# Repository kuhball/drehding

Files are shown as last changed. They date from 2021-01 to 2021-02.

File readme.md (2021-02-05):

# Dreh Ding
An optical illusion.

- [platformio/](platformio/) - the project's code; developed with [platform.io](https://platformio.org/) framework
- [arduinoide/](arduinoide/) - code for the Arduino IDE
	- [tests/](arduinoide/tests/) - component tests, mainly for debugging purposes
	- [legacy/](arduinoide/legacy/) - legacy code, kept to look up old coding patterns
	- [sandbox/](arduinoide/sandbox/) - various code snippets in various states
- [ui/](ui/) - python template code to communicate with the microcontroller
- [fritzing/](fritzing/) - hardware connection diagrams and components created with [Fritzing](https://fritzing.org/)
- [images/](images/) - images for the readme

### Documentation
- [flasheffects.md](flasheffects.md) - A collection of different flash effects that could be programmed.
- [exhibition.md](exhibition.md) - Collection of ideas for installations and performances based on the project.
- [notes.md](notes.md) - Various notes and remarks which have no better place.
- [ideas.md](ideas.md) - Random ideas and notes and such. Can be deleted at any time.

## The project
**Dreh Dings** develops around the [stroboscopic effect](https://en.wikipedia.org/wiki/Stroboscopic_effect). The idea is to place a rotating geometrical object (e.g. a cube) in the centre of a stage and light it at specific intervals with flashes from a number of surrounding LED lights. By varying the flash intervals, various optical illusion effects can be generated. See the following images for a high level schema:

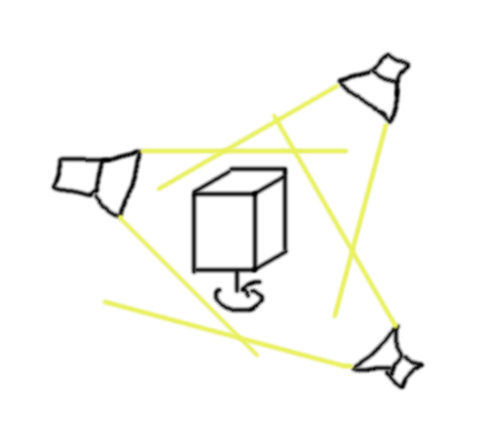
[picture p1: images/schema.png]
High level schema


The project is realized through a number of hardware components and a microprocessor for controlling. Basically, the object turns on a motor whose speed we can modulate. The motor additionally contains a hall sensor (speedometer, clock) to measure the rotation speed. The hall sensor's signal is then used to flash the LEDs at the desired intervals.

The most simple flash configuration is be to flash a single LED always at exactly the same fraction of the object's rotation. Since the object is only illuminated when in the same position, it appears stationary to the observer.

More advanced and interesting flash configurations are also possible.

## Set-up
Navigate to [arduinoide/releases/](arduinoide/releases/) and follow the instructions.

## The software
Coding is done with the [platform.io](https://platformio.org/) framework. Ideally integrated into VSCode as IDE. For every release, an Arduino IDE compatible source code folder is also created.

## The hardware
See [hardware.md](hardware.md).

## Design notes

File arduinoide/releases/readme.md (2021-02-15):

# Releases
Collection of releases for fast deployment.

## How-to
This section describes how to set up the project and get it to run the fast way.

1. Pick a release below.
2. Set-up the hardware according to the connection diagram of the release
3. Download the files in the releases `Drehdings/` folder
4. Open the `Drehdings.ino` with the Arduino IDE
5. Change the settings in the configuration section to match your set-up
6. Compile and upload to the microcontroller
7. Enjoy!

## Releases

### [2021-03-15 Glossy Grape](20210215GlossyGrape/)
A set-up with three LEDs, a rotary encoder to control the motor speed, and a push button to loop through the effects. Does not support gear ratio. Only includes a small number of effects. Mainly intended to try the configuration.

**Usage:**
- Turn knob of rotary encoder to start the motor and to control the motor speed.
- Use push button on rotary encoder to iterate through the LEDs' effects.

**Changelog:**
- switched from Encoder.h to SimpleEncoder.h library
- added Effect-class based LED effects
- fixed glitches that sometimes lead to memory leaks
- added all dependencies directly to the code to avoid Arduino IDE library version issues

**Diagram:**
Same as for release `20210205AbsoluteZero` below.

### [2021-03-05 Absolute Zero](20210205AbsoluteZero/)
A set-up with three LEDs, a rotary encoder to control the motor speed, and a push button to loop through the effects. Does not support gear ratio. Only includes a small number of effects. Mainly intended to try the configuration.

**Usage:**
- LED1 and LED2 will create two slowly turning images of the objects turning in opposite directions.
- Turn knob of rotary encoder to start the motor and to control the motor speed.
- Use push button on rotary encoder to alternate the third LEDs point of flicker (from 0 to 45 degree and back)

**Diagram:**
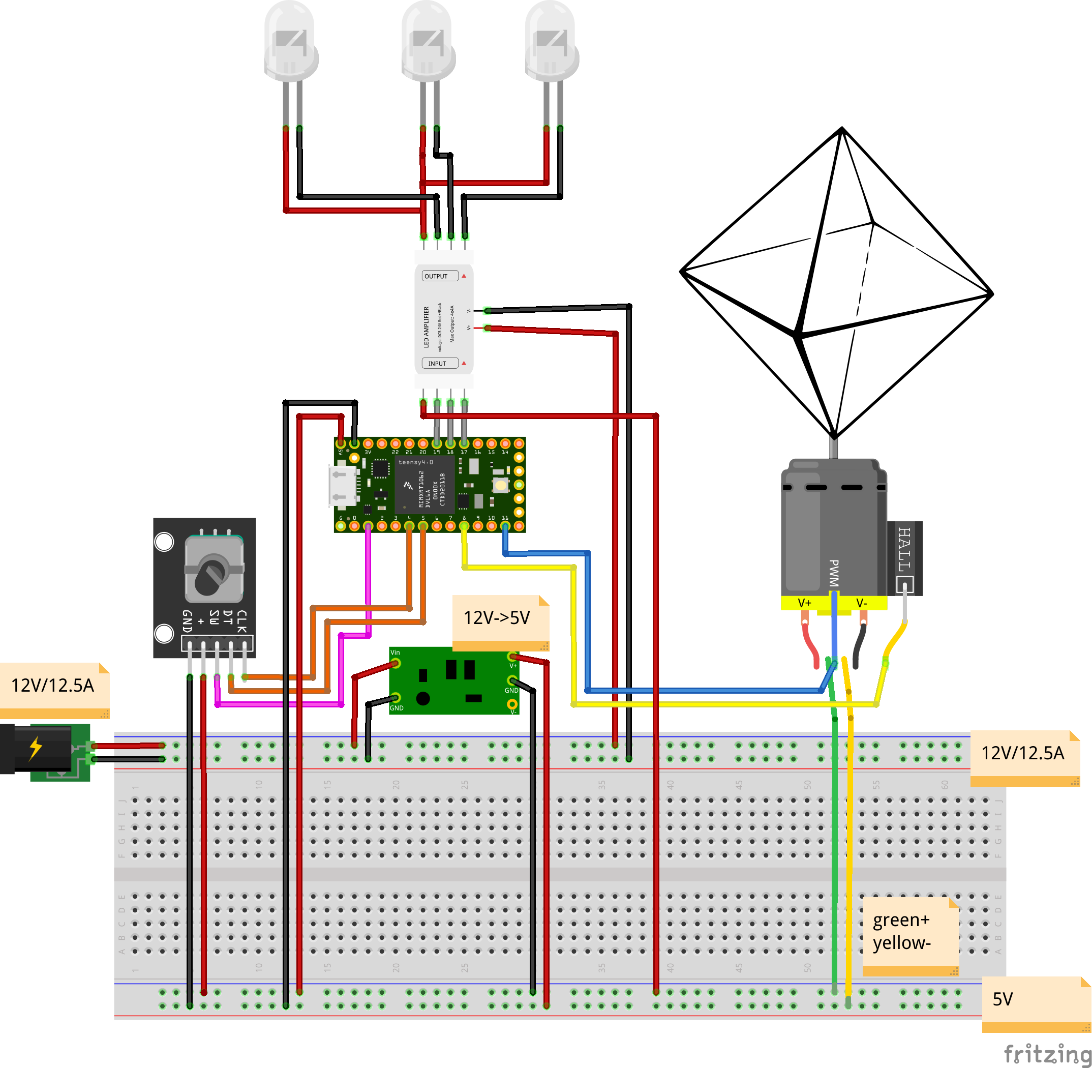
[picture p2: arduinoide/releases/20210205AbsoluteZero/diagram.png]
Connection diagram


## Create a new release

1. Make sure that the code is working well (testing)
2. Choose a name, all releases are named after [colours](https://en.wikipedia.org/wiki/Lists_of_colors)
3. Create a folder under `arduino/releases/` names `YYYYMMDDColour`
4. Copy the `main.cpp` and all library files (`.h` and `.cpp`) to a `Drehdings/` subdirectory
5. Rename `main.cpp` to `Drehdings.ino`
6. Open `Drehdings.ino` in Arduino IDE, compile, upload, and test
7. Create a hardware connection diagram with [Fritzing](https://fritzing.org/) and export as PNG/SVG to release folder
8. Create a new release section in this file and describe the release

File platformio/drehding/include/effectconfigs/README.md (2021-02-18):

# Effect configs
A collection of configuration files that define effect sequences for the project. Allows for easy switching between different effect configurations.

To select one, include it in the `main.cpp` with

```cpp
#include "effectconfigs/example.h" 
```

## How to make your own
See [example.h](example.h) for a detailed example. Then simply copy the file and adapt to your needs.

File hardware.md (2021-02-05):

# Hardware

## The connection diagram

Connection diagram

## The components

#### The microcontroller
The microcontroller lies at the core of the project. Here, all the input signal are gathered and the output signals send to the various components to ensure a seamless interaction. Any programmable microprocessor with digital and at least one analogue PIN can be employed. We use [Arduinos](www.arduino.cc) variants, specifically the [Teensy 4.0](https://www.pjrc.com/store/teensy40.html) for their size and simplicity.

#### The DC motor
The [DC motor](https://en.wikipedia.org/wiki/DC_motor) rotates the illuminated object. It should be powerful enough to drive it fitfully. And it should be of sufficient quality to minimize vibrations, as these weaken the stroboscopic effect. We also want to control the motor's rotation speed, which is usually realized through a [PWM](https://en.wikipedia.org/wiki/Pulse-width_modulation) input. Additionally, the motor should contain a speedometer, usually a hall sensor (see below for more details on this component). All of these controls are already included in modern fan motors, which are therefore our motors of choice.

A typical specification sheet of a fan motor can e.g. look as follows:

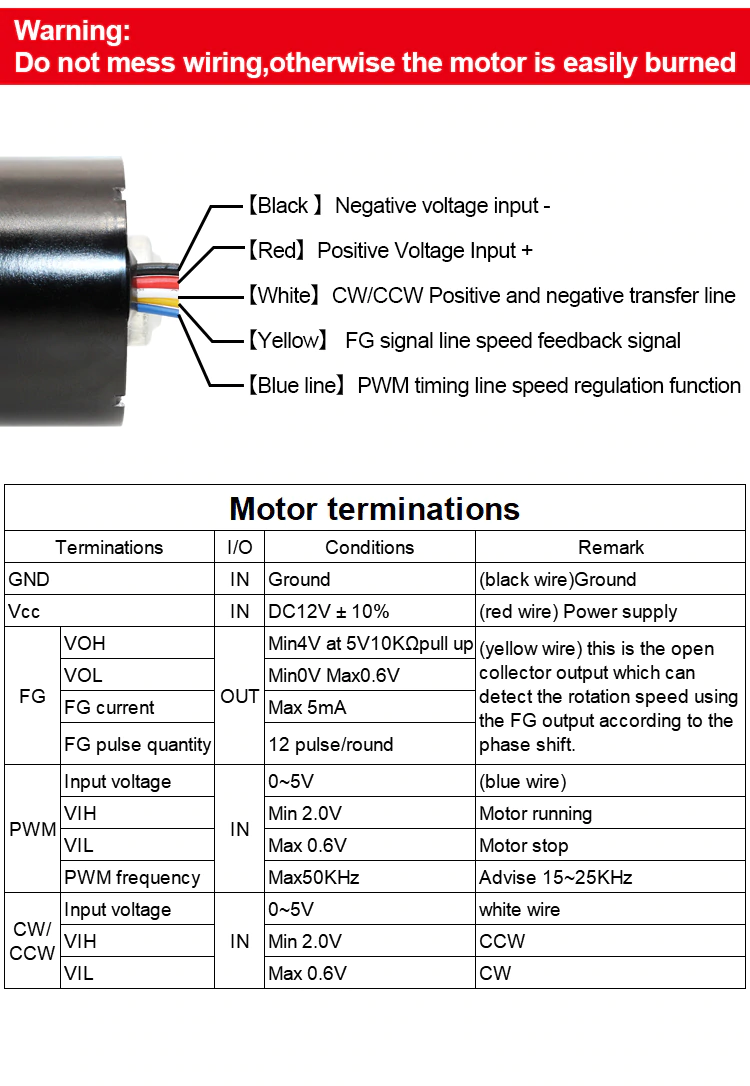
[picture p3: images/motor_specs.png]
Motor specifications example


##### Power supply
Here the black and red wires. Arduino's can only supply 3V or 5V, hence you will need an additional power supply to drive the motor and the LEDs. Take care to keep the power lines separated: Supplying too high voltage to the Arduino or a voltage over 3V to one of the Arduino's input pins can destroy the processor. All ground wires should be connected to the same line, though.

##### Speedometer / hall sensor
Here the yellow wire. Analogue output that sends a PWM signal. See below for more details.

##### Rotation speed control
Here the blue wire. Analogue input that expects a PWM signal. This signal is then averaged, and [the average voltage received determines the motor's rotation speed](https://www.electronics-tutorials.ws/blog/pulse-width-modulation.html).

We employ a rotary encoder to control the motor speed.

##### Rotation direction control
Here the white wire. Digital input that expects a high or low signal. Depending on the signal, the motor turn clockwise (CW) or counter-clockwise (CCW). We do not make use of this wire.

#### The (incremental) rotary encoder
A [rotary encoder](https://en.wikipedia.org/wiki/Rotary_encoder) is essentially a turning knob. We can capture in which direction it turns and change a variable accordingly. A detailed description of it' working can be found [her](https://lastminuteengineers.com/rotary-encoder-arduino-tutorial/).

Here we use it to control the motor speed by changing the PWM signal's duty cycle.

Since the rotary encoders signal is not very clean, it cannot be used for discrete changing of states, as e.g. controlling the LED effects. Even with software de-bouncing activated.

Our rotary encoder (model KY-040) also incorporates a push button. See there for more details.

#### The hall sensor (build into the motor)
A hall sensor is a device to measure the magnitude of a magnetic field. To understand how the sensor works in this setup, we must first look at the DC motor's inner workings:

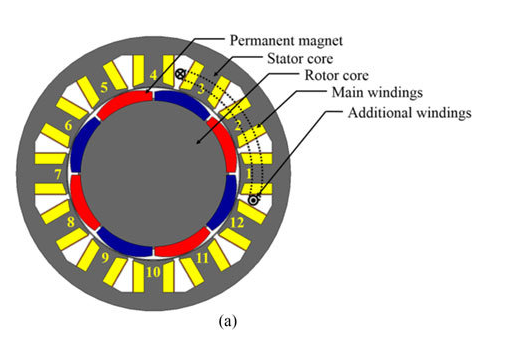
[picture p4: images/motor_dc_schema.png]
DC motor schema


The *stator* is the stationary casing, the *rotor* the movable inner element. The former contains wire *windings*, the latter is covered with a number of *permanent magnets* with alternating polarity. When power is supplied, the wirings are switched on and off in order, creating a magnetic current that attracts or repels the permanent magnets depending on their polarity, and, ultimately, causes the rotor to turn. There are other types of DC motors, but they work similarly.

Now let's look at an equivalent schema, but with an hall sensor added:

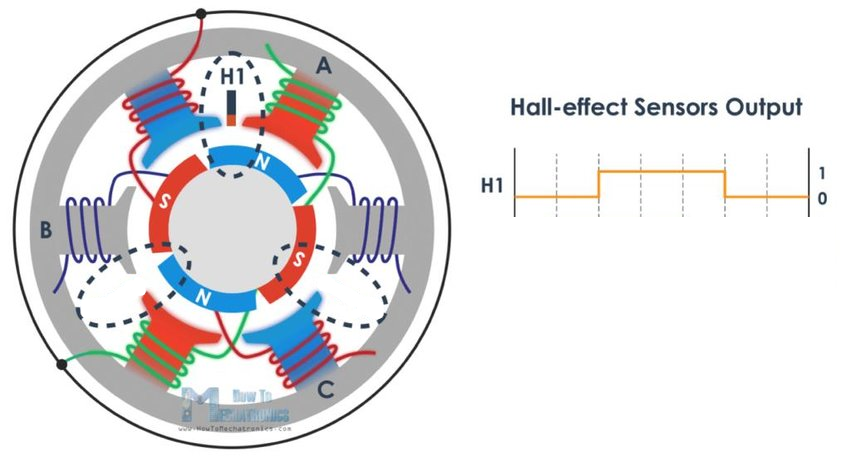
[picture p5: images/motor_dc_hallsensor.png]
DC motor schema with hall sensor


The *hall sensor* (H1) is placed at a fixed position between two wirings in the stator. Every time a permanent magnet passes, it registers a change in the magnetic field. Or, more simple, when it has an N-polarity magnet in front of it, it creates an output. And when it has an S-polarity magnet in front of it, it does not create an output. When the motor is rotating, the permanent magnets pass continuously in front of the hall sensor, causing it to generate a PWM signal as can be seen on the right.

The generated PWM has a fixed-length duty cycle of 50% (aka it is on 50% of the signal time), since the permanent magnets are of equal length. It's frequency (rate), on the other hand, depends directly on the motor's rotation speed. That's why the signal can be utilized as a speedometer.

When connected to an input pin of the microcontroller, we will see a LOW->HIGH signal transition each time a N->S permanent magnet transition passes in front of the hall sensor. And a HIGH->LOW signal transition each time a S->N permanent magnet transition passes in front of the hall sensor (Not sure about the N->S, S->N order, though. But it doesn't matter for our application). These are usually captured with hardware interrupt signal in the microcontroller's code (more on this in the code section). Important is, that to know the rotation speed of the motor, we must know the number of permanent magnets it contains, as these determines the number of signals we will receive per motor rotation.

This value should be given in the motor specifications. If it is not supplied, you can find some code in the [tests/](tests/) folder to experimentally determining the number. Usual values are somewhere between four and 24 magnets. If you count only the LOW->HIGH or the HIGH->LOW transitions, you will receive exactly half the number of signals. If you count both, you will receive as many signals as there are permanent magnets.

Although unusual, some motors have e.g. 18 permanent magnets, which results in an uneven number of nine signals when counting only the LOW->HIGH transitions. In these cases it might be advantageous to count all transitions to achieve a signal number of 18, which is easier dividable.

##### Pull up resistor
The hall sensor must be connected to it's pin with a pull-up resistor set-up, as shown in the following image:

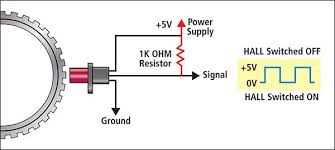
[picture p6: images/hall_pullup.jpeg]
Hall sensor pull-up schema


This is necessary, as the signal it produces is relatively unstable and of varying and (probably) unknown voltage. Furthermore, this causes a noise signal on the wire if the hall sensor is of (aka the motor not turning). Such a pull-up resistor set-up [can also be enabled on the microprocessor directly](https://www.arduino.cc/en/Tutorial/BuiltInExamples/InputPullupSerial), without the need of an external resistor and additional power supply. Simply set the chosen [digital input pin](https://www.arduino.cc/en/Tutorial/Foundations/DigitalPins) as follows:

```cpp
pinMode(PIN_HALL, INPUT_PULLUP);
```

Note that this will invert the HIGH and LOW signals.

##### Pin 13 or the LED pin
Most Arduino boards have one pin (usually 13) with a directly connected LED. This is a useful set-up to visually confirm that a signal arrives at the pin. But the hard-wired LED makes it a unsuitable choice for a pin in `INPUT_PULLUP` mode. Don't use this particular pin as input for the hall sensor.

#### The LEDs, with LED amplifier board
Since the LEDs require more power than the microcontroller can provide, they are not directly connected to it, but rather to an LED amplifier board. That way, an external power supply can drive the LEDs safely and reliably. The connection to the microcontroller's pin can be either a source or a sink. If pin is used as LED sink, you set the register of the pin to LOW to turn the LED on. And vice-versa.

For maximum effect variability, choose LEDs of different colours in different positions.

The pins should be digital. We put them OUTPUT mode and set to one level (HIGH or LOW) to switch the LED on. And to the other level to switch it off.

#### The (effect) push button
We employ a push button to loop through the different LED effects. In above diagram, this button is integrated in the rotary encoder, but a separate push button can be used just as easily.

Every time the button is pressed the LED's change their LED effects according to a pre-defined effect loop. Note that we employ software de-bouncing.

#### The power supply
The microcontroller itself can be supplied with power through the USB connection. If you want to run the set-up also separated from the PC, you will have to supply power from another source, too. Since both, the motor and the LEDs, are ideally also supplied by an external power supply, you can supply all components together, as long as their requirements match.

The LEDs and the motor run at 12V. The microcontroller is supplied with 5V. The rotary encoder requires 3-5V. And all PINs deliver ad consumer 3V.

Note that all sinks should be connected, even if multiple power sources are used.

See the schemas in the project variants below for the exact set-up.

#### The rotating object
The object can be anything. Depending on its shape, you can achieve different stroboscopic effects. Typical choices are 3D geometrical shapes, such as cubes, octahedrons, tetrahedrons, etc. But you can also mount a 3D printed anime figurine on the motor, if you wish.

## Hardware variants

### Hardware variant I (Oskar's small setup)

- microcontroller is Teensy 4.0, Arduino compatible (see [her](https://www.pjrc.com/store/teensy40.html) for PIN specifications)
- [motor specifications](https://ae01.alicdn.com/kf/HTB1I91_IpXXXXb9XpXXq6xXFXXXc/221879944/HTB1I91_IpXXXXb9XpXXq6xXFXXXc.jpg)
	- Note that no FG singal is described here. In the specs of the bigger motor (https://ae01.alicdn.com/kf/H9b7d23087b9f4301bd53cda0bcdb2bbfT.jpg) it is.
	- The smaller nevertheless does have a tacho that sends a signal on the yellow cable (we measured it)
	- Experimentation revealed: hall sensor has 9 LOW->HIGH signal per rotation, that means 18 if also HIGH->LOW is measured
- LEDs
	- A HIGH signal switches them off, a LOW switches them on!
	- The fastest still visible flash (on time interval) is 100 microseconds aka 0.1 milliseconds

### Hardware variant II (Chris' large setup)

- [motor specifications](https://ae01.alicdn.com/kf/H9b7d23087b9f4301bd53cda0bcdb2bbfT.jpg)

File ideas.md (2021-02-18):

# Ideas
Random ideas and notes and such. Can be deleted at any time.

- [X] allow another rotation angle resolution than degrees
- [X] put main config in own header file
- [X] put sequence definitions in own files that can be included to select a sequence composition 
- [ ] add function based effect sequence
	- set a overall time for the effect
	- then write a function f(ellapsedTime) = activation angle
		- aka a function that determines the flash position based on where in the sequence we are
	- test e.g. with a sin(x) function suitably defined
- [ ] make code in libs/ into proper libs with versioning
- [ ] check all interrupt routines is follow the programming guides: https://www.pjrc.com/teensy/interrupts.html
- [ ] find a better way to inject LED effects (should be add effect and that's it)
- [ ] find a better way to determine number of LED's (not in code, should iterate over array somehow; but caused memory glitches in first attempt)
- [ ] lookup strobe-gifs and get inspired and try some patterns
- [ ] designs some nice and organic effect configurations
- [ ] rewrite timers to use Teensy specific timer settings (not micros, rather https://www.pjrc.com/teensy/td\_timing.html, e.g. ellapseMicros)
- [ ] when +/- stable function, rewrite code to speed up (if required); update: doesn't seem like it
- [ ] re-write in micropython or circuitpython?
- [X] write a sequence flashing processor [done]
	- aka tell each LED at which tick to flash and for how long in millis
	- allows for flexible flash configuration testing
	- e.g.
		- LED1_ticks = [0,8,4,7]
		- LED1_intervals = [500, 100, 200, 500]
	- wraps around after the end
- [X] write a function to determine the rounds-per-minute/second/micros
	- count interrupts with interrupt counter
	- add computeRpm function to loop
	- uses time to read time passed, reads interrupt counter, divides by interrupts-per-round, divides by time in seconds, rounds
	- returns rpm/rps
- [X] write function that flashes LED at flashes / round
	- we know the rps value
	- means LED should flash X=s/rps times per second
	- implement with micros/millis
- [X] add fraction delay form round start [not required, starting point is first hall signal]
	- somehow synchronize starting point of LEDs time in previous function
	- then flash them again X times
	- but shift starting point by a milli/micro value
	- should cause unsynced LEDs
- [X] loop() called ca. at 117 kHz aka 117,000 times/second? [can ignore, time based flashing works very well, processor obviously fast enough]
	- Could be more or less, depends on board, code in loop, etc.
	- Not a good value to build anything on. Use rather micro or milliseconds
- [X] write time-based version of code
	- measures rotations-per-micros
	- controls LEDs with parameters:
		- flash each fraction (<1) or multiple (>=1) of rotations
	- provides better granularity control
	- might de-sync after some runtime [does not, works perfectly]
		- figure out a way to re-sync with hall signal from time to time
- [X] write an LED class
	should contain LED functionality, counters, steering methods, parameters, etc.
- [X] change to measure also HIGH->LOW with interrupts -> better number (18 instead of 9) for dividing

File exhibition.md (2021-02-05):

# Exhibition
Collection of ideas for installations and performances based on the project.

### Handheld
- Big room or forest, many turning devices all over the place, some maybe hidden in the trees or dark corners. General lightning subdued up to dark.
- Everyone who enters gets a handheld device, which is essentially a strobo
- When pressing the trigger, a random flash sequence starts that continues as long as the trigger is pressed
- It can be pointed at any turning object, creating an effect, the exact effect depends on object and flash sequence
- Visitors can combine their sequences on an object, creating new effects
- Every time the trigger is released and pressed again, a new random sequence starts

Remarks on this:
- all motors must turn with same speed and must be of same type
- sending the current hall sensor tick over the air might be to slow
	- if it is, then we must use a cable based handheld version
	- then every station would have their own 1-3 handheld devices

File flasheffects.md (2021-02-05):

# Flash effects
A collection of different flash effects that could be programmed.

- describe different configurations for the flashes here and what effects they cause
- depends on objects used
- see also [stroboscopic effect](https://en.wikipedia.org/wiki/Stroboscopic_effect)

- single LED flash = stationary object
- multiple LED flash = multiple interleaved stationary objects
	- not very distinguishable, maybe requires different LED colours or bigger object
- single LED flash, then slowly changing flashpoint = stationary object that slowly moves
- two LEDs flash, then slowly changing flashpoints, both in opposite directions = two stationary objects rotating against each other
	- looks very nice with time-based flashing
- one LED at it's flashpoint on; after some time, switch off and second on, then off and third on, usw.
	- first long on-times for each LED; then shorter, then longer again
	- = multiple objects switching in and out, sometimes faster, sometimes slower
- put an object on one side of the octahedron
	- = can we make that appear and disappear by using a single LED and switching flashpoints?
		- yes, looks very nice
	- works well with face put one two side (one smiling, one frowning)
- face on one side
	- make it move by one LED, stationary with another
	- make object side without face stationary, then shortly blink over to face (shock), then off again
		- maybe at random intervals, so observers have to wait
- other objects on one or more sides
	- can cause interleaving and spiralling effects
- mount other objects on the motor
	- I would fancy a spiral
	- Try first with Küchenmaschiene
		- Looks nice with Kuechenmachine
		- Keep object motor running two: PWM can be used to change flashing speed until matches Kuechenmachine
- softstart motor (start slow, then to target speed)
- faces on two sides
	- one smiling, one sad
	- two leds, both faces smiling
	- from time to time, one flips to sad state
	- look nice!
- now that lamps are restricted in where they can shine: Place one to highlight the upper, another to highlight the lower part of the object. Idea by Christ (works, try some more Oskar)
	- looks nice with both sides moving in opposite directions

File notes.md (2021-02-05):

# Notes
Various notes and remarks which have no better place.

## Interrupt pins
All input pins can be designated as interrupt pins. But there are some dedicated hardware interrupt pins that could also be used. Not sure if one has an advantage over the other.
able (we measured it). How exactly it is defined remains a mystery.

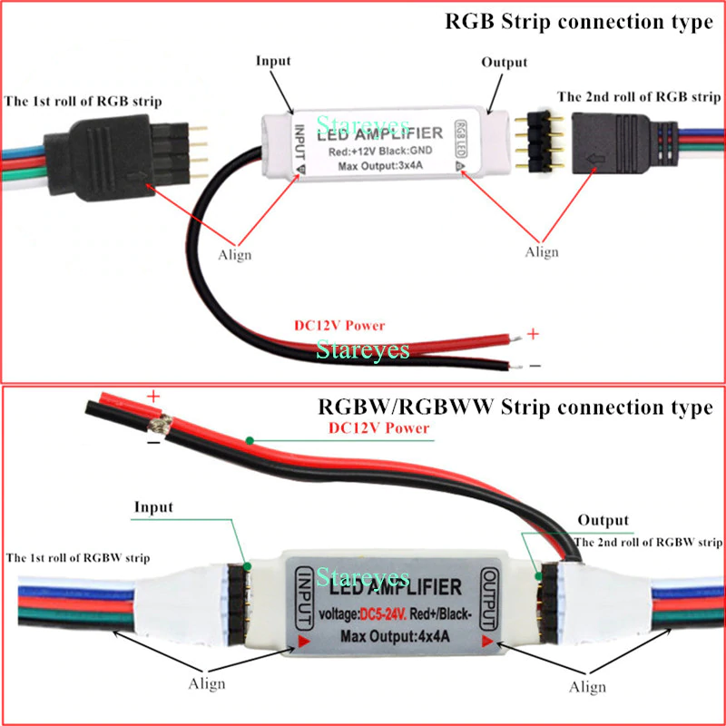
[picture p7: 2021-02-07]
images/amplifierconnection.webp

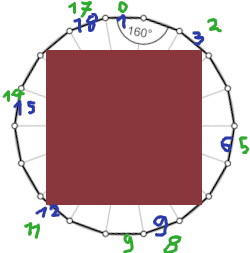
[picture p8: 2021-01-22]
images/octadecagon.png

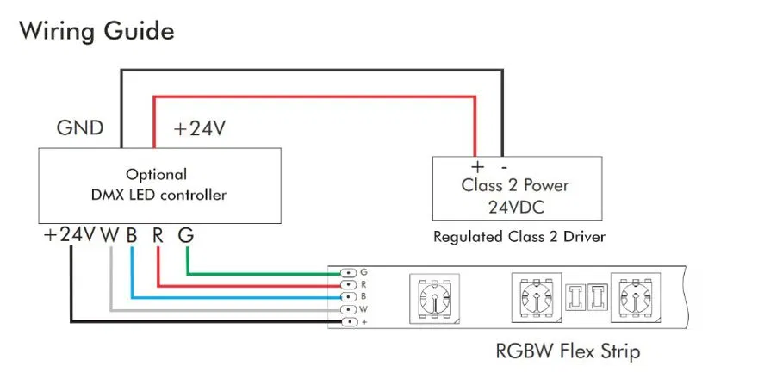
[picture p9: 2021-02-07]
images/rgbwconnector.webp

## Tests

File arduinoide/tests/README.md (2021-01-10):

# Sandbox
Collection of scripts to test or measure various in- and outputs or processor functions.

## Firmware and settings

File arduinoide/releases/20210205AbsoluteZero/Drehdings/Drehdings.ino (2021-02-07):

/**
 * DrehDings project.
 * 
 * A turning geometrical object is highlighted by LED flashes at
 * regular intervals, producing an optical illusion of stationary
 * versions of the object.
 * 
 * This version flashed the LEDs based on object rotation speed
 * derived from the ticks per round measured by a
 * hallsensor (tacho) as the motor turns the object.
 */
#include "Arduino.h"
#include "Encoder.h"
#include "Bounce.h"

#include "Motor.h"
#include "HallTimed.h"
#include "Led.h"


/*** START: CONFIGURATION **/

// pin setup
// for all: do not use the pin with the board LED attached (usually 13)
// for all: use only digital PINs
// @see https://www.pjrc.com/store/teensy40.html for PIN diagram
#define PIN_MOTOR 11  // motor speed control, use pin that is PWM enabled
#define PIN_HALL 8  // motor's hallsensor's signal, usually termed FG
#define PIN_LED1 17
#define PIN_LED2 18
#define PIN_LED3 19
#define PIN_ENCODER_CLK 4  // rotary encoder's CLK signal, also called A signal
#define PIN_ENCODER_DT 5  // rotary encoder's DT signal, also called B signal
#define PIN_ENCODER_SW 1  // either signal of rotary encoder's integrated push-button or any other push-button

// base configuration
#define HALL_TICKS_PER_TURN 18  // how often the hall-sensor sends a pulse per turn; a hardware constant; see hall-sensor specification or tests/hallsensorpulses
#define MOTOR_PWM_HZ 100  // frequency of the PWM signal driving the motor; a hardware constant; see motor specification
#define GEAR_RATIO 1.0  // if gearing employed, set this to the ratio; >1.0 means object turns faster than motor, <1.0 means object turns slower than motor

// effect configurations
// LED1 (CW) and LED2 (CCW) rotation configuration
static const uint32_t change_millis = 100;  // after how many millis to change
static const uint16_t speed_degree = 1;  // how many degrees to change

/*** END: CONFIGURATION **/


// LED objects init
Led leds[3] = {
  Led(PIN_LED1, true),
  Led(PIN_LED2, true),
  Led(PIN_LED3, true)
};

// controll objects init
HallTimed hall(PIN_HALL, HALL_TICKS_PER_TURN);
Motor motor(PIN_MOTOR, MOTOR_PWM_HZ);
Encoder motorspeed(PIN_ENCODER_CLK, PIN_ENCODER_DT);
Bounce button = Bounce(PIN_ENCODER_SW, 50); 

// rotation variables
uint32_t last_change = 0;
uint16_t current_degree = 0;

// speed control variables
uint8_t speed = 0;


/**
 * Function called on interrupt.
 */
void isr() {
  hall.handle_interrupt();
}

/**
 * Setup the routine.
 */
void setup() {
  // init motor speed controll
  motorspeed.write((int32_t)Motor::DUTY_CYCLE_DEFAULT);

  // LED sequence control
  leds[2].flash_at_part = 0;
  last_change = millis();

  hall.set_interrupt_handler(isr);
  sei();  // start interrupts
}

/**
 * Loop execute indefinitiely.
 */
void loop() {
  for (size_t i = 0; i < sizeof(leds); ++i) leds[i].turn_off_cond();

  // object rotation effect steering
  if (millis() - last_change >= change_millis) {
    last_change = millis();
    leds[0].flash_at_part = current_degree;
    leds[1].flash_at_part = 360 - current_degree;
    current_degree += speed_degree;
    if (current_degree >= 360) current_degree = 0;
  }

  // for each LED check if action required at current position
  uint16_t degree = (uint16_t)((float)hall.get_degree() * GEAR_RATIO);  // motor degree to object degree
  while (degree > 360) degree = degree - 360;  // wrap around to ensure valid angle
  for (size_t i = 0; i < sizeof(leds); ++i) leds[i].turn_on_cond(hall.tick_no, degree);

  // adapt motor speed if changed
  const int32_t encoder_pos = motorspeed.read();
  const uint8_t speed_new = constrain(encoder_pos, 0, 255);
  motorspeed.write((int32_t)speed_new);
  if (speed_new != speed) {
    motor.set_speed(speed);
    speed = speed_new;
  }

  // react to button press (LED3 effect)
  if (button.update()) {
    if (button.fallingEdge()) {
      if (leds[2].flash_at_part == 0) {
        leds[2].flash_at_part = 45;
      } else {
        leds[2].flash_at_part = 0;
      }
    }
  }
  
}

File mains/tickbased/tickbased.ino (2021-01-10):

/**
 * DrehDings project: tick-based version.
 * 
 * A turning geometrical object is highlighted by LED flashes at
 * regular intervals, producing an optical illusion of stationary
 * versions of the object.
 * 
 * This version flashed the LEDs based on ticks per round measured
 * by a hallsensor (tacho) as the motor turns the object.
 */

// pin setup (all digital)
#define PIN_MOTOR 3  // motor speed control
#define PIN_HALL 14  // do not use the pin with the board LED attached (usually 13)
#define PIN_LED1 4
#define PIN_LED2 5
#define PIN_LED3 6

// base configuration
#define HALL_PULSE_PER_TURN 9  // how often the hall-sensor sends a pulse per turn; a hardware constant; see hall-sensor specification or tests/hallsensorpulses
#define LED_INTERVAL_ON 300    // time the LEDs should stay on in microseconds; choose lowest value that still produces sufficient illumination; see tests/determineledminblinktime
#define MOTOR_PWM_HZ 100       // frequency of the PWM signal driving the motor; a hardware constant; see motor specification

// flash configuration
// _pos : when the motor is in this position (one of [0, HALL_PULSE_PER_TURN)), the LED flashes
// _cooldown : wait this many motor rotations after each flash before flashing again; default is 0
static const uint8_t led_1_pos = 0;
static const uint8_t led_1_cooldown = 0;
static const uint8_t led_2_pos = 3;
static const uint8_t led_2_cooldown = 0;
static const uint8_t led_3_pos = 6;
static const uint8_t led_3_cooldown = 0;

// motor configuration
static const uint8_t motor_pulse_length = 40;  // which fraction of the motor's PWM signal to send HIGH; [0,255]; determines motor turning speed


// variables (do not change)
unsigned long led_1_switched_on = 0;  // time when last switched on
unsigned long led_2_switched_on = 0;
unsigned long led_3_switched_on = 0;

uint8_t led_1_c = 0; // cooldown counter
uint8_t led_2_c = 0;
uint8_t led_3_c = 0;

volatile uint8_t motor_position = 0;  // interrupt counter; rather used as motor position state aka in which phase of a turn it is; takes values in [0,HALL_PULSE_PER_TURN)
volatile uint8_t motor_position_changed = 0;  // reqired when motor is turned manually to avoid multiple reactions to the same motor position state


/**
 * Function called on interrupt.
 */
void isr() {
  motor_position++;
  motor_position_changed = 1;
}

/**
 * Turns all LEDs off that have been on for LED_INTERVAL_ON microseconds or longer.
 */
void leds_turn_off() {
  const unsigned long current = micros();
  if (current - led_1_switched_on >= LED_INTERVAL_ON) digitalWrite(PIN_LED1, HIGH);
  if (current - led_2_switched_on >= LED_INTERVAL_ON) digitalWrite(PIN_LED2, HIGH);
  if (current - led_3_switched_on >= LED_INTERVAL_ON) digitalWrite(PIN_LED3, HIGH);
}

/**
 * Setup the routine.
 */
void setup() {  
  // setup pins
  pinMode(PIN_MOTOR, OUTPUT);
  pinMode(PIN_HALL, INPUT_PULLUP);
  pinMode(PIN_LED1, OUTPUT);
  pinMode(PIN_LED2, OUTPUT);
  pinMode(PIN_LED3, OUTPUT);

  // create PWM singal for motor
  analogWriteFrequency(PIN_MOTOR, MOTOR_PWM_HZ);
  analogWrite(PIN_MOTOR, motor_pulse_length);  // 0-255 aka 0-100% of duty cycle on

  // create interrupt on hall-sensor pin when high pulse is received
  attachInterrupt(digitalPinToInterrupt(PIN_HALL), isr, RISING);
  sei();  // start interrupts
}

/**
 * Loop execute indefinitiely.
 */
void loop() {
  leds_turn_off();

  if (motor_position >= HALL_PULSE_PER_TURN) motor_position = 0;  // go repeatedly through motor positions states

  if (motor_position_changed > 0) {  // only act if there has been a change since last action
    motor_position_changed = 0;
    
    if ((motor_position == led_1_pos) && (led_1_c >= led_1_cooldown)) {  // if in right position and cooldown passed
      digitalWrite(PIN_LED1, LOW);  // switch LED on
      led_1_c = 0;  // reset cooldown
      led_1_switched_on = micros();  // set timestamp
    } else if (motor_position == led_1_pos) {  // skip one turning of the motor
      led_1_c++;
    }

    if ((motor_position == led_2_pos) && (led_2_c >= led_2_cooldown)) {
      digitalWrite(PIN_LED2, LOW);
      led_2_c = 0;
      led_2_switched_on = micros();
    } else if (motor_position == led_2_pos) {
      led_2_c++;
    }

    if ((motor_position == led_3_pos) && (led_3_c >= led_3_cooldown)) {
      digitalWrite(PIN_LED3, LOW);
      led_3_c = 0;
      led_3_switched_on = micros();
    } else if (motor_position == led_3_pos) {
      led_3_c++;
    }
  }
}

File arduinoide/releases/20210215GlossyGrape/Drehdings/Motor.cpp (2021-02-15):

#include "Arduino.h"
#include "Motor.h"

const uint8_t Motor::DUTY_CYCLE_RESOLUTION = 8;
const uint8_t Motor::DUTY_CYCLE_DEFAULT = 127;

Motor::Motor(uint8_t pin, uint64_t frequency)
    : frequency(frequency),
      _pin(pin),
      _duty_cycle(Motor::DUTY_CYCLE_DEFAULT)
{
    pinMode(_pin, OUTPUT);
    //analogWriteResolution(Motor::DUTY_CYCLE_RESOLUTION);  // currently not implemented
    analogWriteFrequency(_pin, frequency);
    analogWrite(_pin, 0UL);  // 0-255 aka 0-100% of duty cycle on; start stopped
}

void Motor::start() {
    analogWrite(_pin, _duty_cycle);
}

void Motor::stop() {
    analogWrite(_pin, 0UL);
}

void Motor::set_speed(uint8_t speed) {
    _duty_cycle = speed;
    start();
}

void Motor::inc_speed(uint8_t val) {
    _duty_cycle = (_duty_cycle + val <= 255) ? _duty_cycle + val : 255;
    start();
}

void Motor::dec_speed(uint8_t val) {
    _duty_cycle = (_duty_cycle - val >= 0) ? _duty_cycle - val : 0;
    start();
}

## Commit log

2021-01-22 Switched to platform.io based development environement.
2021-01-25 Added a hall turning speed test script.
2021-01-29 Hall sensor now timer based instead of tickbased for higher resolution.
2021-02-02 Added rotary encoder tests.
2021-02-02 Some sandbox scripts connected with the rotary encoder and its button.
2021-02-02 Rotary encoder now controls motor speed.
2021-02-02 Added link to rotary encoder tutorial.
2021-02-04 Created a connection diagram.
    [main.fzz]
2021-02-05 Added code to catch button press.
2021-02-05 Reworked the repository structure and cleaned up heavily.
    [main.fzz]
2021-02-05 Cleaned fritzing folder 2.
    [sandbox.fzz]
2021-02-05 First release: 20200205AbsoluteZero
    [20200205AbsoluteZero.fzz]
2021-02-07 Fixed error in wiring diagram.
    [20200205AbsoluteZero.fzz]
2021-02-07 Added a gear ratio setting.
2021-02-15 Added test for controlling the motor speed with an encoder.
2021-02-15 Added inc_speed() and dec_speed() to motor class.
2021-02-15 Hall sensor now disabled interrupt while reading/writing volatile variables.
2021-02-15 Fixed memory problem, was caused by LED object array.
    [main.cpp]
2021-02-15 Introduced changeable Effects per LED.
2021-02-15 Encoder button debounce test added (not required anymore with new encoder lib version).
